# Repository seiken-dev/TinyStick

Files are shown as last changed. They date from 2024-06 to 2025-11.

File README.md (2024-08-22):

# TinyStick
<p align="center">
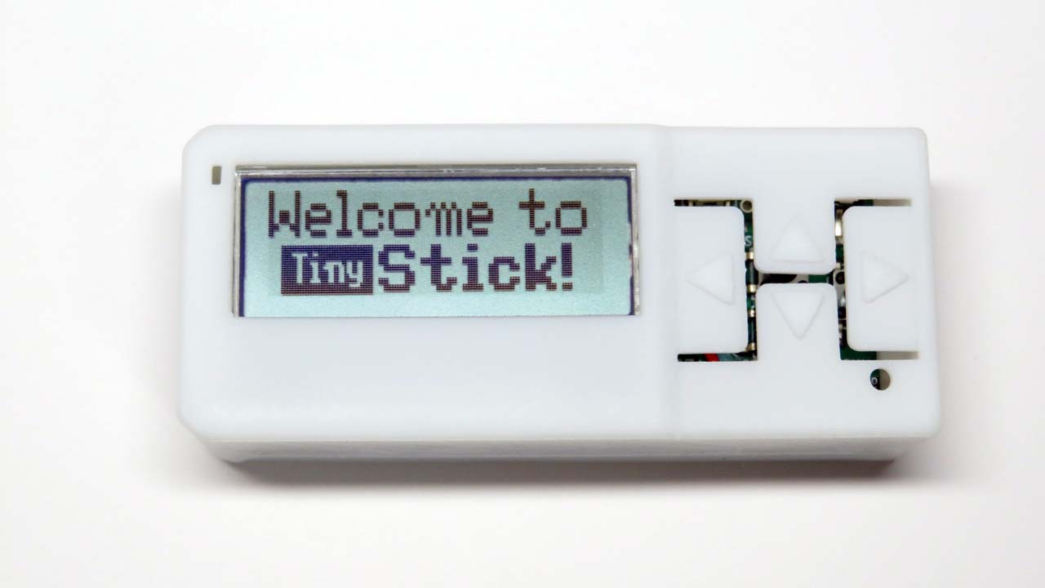
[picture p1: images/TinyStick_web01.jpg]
TinyStick

</p>

**TinyStick**は、**ATtiny3217**(32KB Flash, 2KB SRAM, 256B EEPROM)を搭載した、Arduino互換の開発キットです。消費電流は約4.5mA(クロック10MHz。スリープ時は0.1mA未満)と小さく、コイン電池で長期間動作します。プログラムの書き込みは、付属の**USBシリアル変換基板**(CH340E搭載)で行います。詳しくは、 [tinystick.jp](https://www.tinystick.jp)をご覧ください。

# コンテンツ
- **Arduino**<br>
PlatformIOでビルドできるデモのソースコードです。
- **KiCad**<br>
[KiCad](https://www.kicad.org/)(7.0)のプロジェクトです。TinyStick本体の**TS_Core.kicad_pro**と、USBシリアル変換基板の**TS_USB.kicad_pro**が含まれます。
- **schematic**<br>
TinyStick本体とUSBシリアル変換基板の回路図PDFです。
- **Blender**<br>
3Dプリントケース作成用のBlenderのプロジェクトファイルと、発注に使用したSTLファイルです。

# プログラミング
**TinyStick**のプログラミングは、[PlatformIO](https://platformio.org/)で行います。[Arduino IDE](https://www.arduino.cc/en/software)は、2.3版ではTinyAVR用のボードマネージャーの定義が読み込めない等の理由で推奨しません。(→[参考](https://ameblo.jp/pta55/entry-12835016734.html))

### ビルド
- **PlatformIO**のプロジェクトフォルダに**Arduino**以下をコピーし、適当な名前(例:TinyStickDemo)に変更します。
- **PlatformIO**の**Home**画面から[**Open Project...**]で、このプロジェクトを開きます。
- 必要なplatform(**Atmel megaAVR**)のインストールが自動的に始まります。
- インストールが完了したら**Build**してください。

### UPDI書き込み
- USBシリアル変換基板をUSBケーブルで接続して、スイッチをオンします(赤いLEDが光ります)。このとき、ドライバを自動認識しない場合は、[メーカーのHP](https://wch-ic.com/search?q=CH340&t=downloads)からCH340のドライバをダウンロードしてインストールしてください。
- Windowsの場合は、デバイスマネージャの「ポート(COMとLPT)」に「USB-SERIAL CH340 (COMxx)」と表示されれば完了です。
- **PlatformIO**の**Upload**をクリックすると、プログラムを転送します。

### シリアルデバッグ
- 横のボタン(**Button5**)を押して「Bounce Ball」デモに切り替えたあと、**PlatformIO**の**Serial Monitor**または**Tera Term**等のターミナルアプリを起動すると、加速度の数値が流れてきます。
- このUSBシリアル変換基板は、ターミナルアプリを起動するとRTS信号がLOWになることを利用して、UPDI書き込みとシリアル通信モードを自動的に切り替えます。(Windowsで確認 →[参考](https://ehbtj.com/electronics/make-serial-updi-programmer/))

### platformio.ini
プロジェクトのルートにある設定ファイルです。重要な項目について説明します。

`board_build.f_cpu = 10000000`<br>
CPUクロックを設定します。初期値は10MHz、最大は20MHzです。必ず5の倍数にしてください。そうしないとシリアル通信が文字化けします。また5MHzにすると、I2Cが正常に動作しません。記述しないと16MHzになります。

### ソースコード
- **main.cpp**<br>
メインプログラムで、初期化、タイトル表示、サイドボタン(**Button5**)によるデモの切り替え、長押しによるバックライトのオンオフを処理します。

- **TinyStickDef.h**<br>
共通の#define、ピン定義です。

- **TinyStick.h .cpp**<br>
ボタン、圧電ブザーのクラス、スリープ関連のグローバル関数です。

- **TinyLCD.h .cpp**<br>
バックライト付きLCD [**AQM1248A**](https://akizukidenshi.com/catalog/g/g110048/)に、ビットマップまたは文字を表示するクラスです。文字は、拡大・ボールド・白黒反転・縦・プロポーショナル表示に対応しています。

- **font8x8.h**<br>
8x8ドットフォントです。0x20から0x7Fまでの英数記号です。

- **TinyApp.h .cpp**<br>
複数のアプリを切り替えるときは、このクラスの派生クラスを作成して**main.cpp**に定義するだけで、サイドボタン(**Button5**)で切り替えられます。

- **I2Cbase.h .cpp**<br>
本体内蔵の加速度センサ(**LIS2DH12**)と、M5StickC用のENV Hat(**SHT30**)の基底クラスです。

- **octave.h**<br>
ドレミの周波数を定義したファイルです。

- **playDigit.h .cpp**<br>
２桁の整数値をドレミの音程で鳴らす関数です。

- **app/**<br>
6つのデモアプリです。**TinyApp**の派生クラスです。
  - **EnvHat.h .cpp**<br>
  **ENV Hat**で温度/湿度を表示します。**Button1**で次のアプリに切り替えます。装着されていないときはスキップします。

  - **KitchenTimer.h .cpp**<br>
  キッチンタイマーです。最大99分。スタートすると、分をEEPROMに保存します。

  - **AccelDemo.h .cpp**<br>
  加速度センサのデモです。傾けると玉が転がります。

  - **FontTest.h .cpp**<br>
  8x8ドットフォントをダンプします。**Button1**で拡大、**Button2,3**でスクロールします。

  - **Tetris.h .cpp**<br>
  お馴染みのゲームで、縦向きで遊びます。

  - **Maze3D.h .cpp**<br>
  Line関数を利用した3次元迷路です。

### スリープ機能
一定時間のスリープが出来ます。いずれかのボタンを押すと、スリープから復帰します。
- 時間は任意の時間ではなく、**TinyStick.h**の`enum SleepTime`の時間しか設定できません。
- 本来PX2,PX6ピンに接続されたボタン(TinyStickではButton1のみ)でしかスリープからの復帰はできませんが、これは**FALLING**モードの場合で、**LOW**モードならどのボタンでも復帰が可能です。このため、**LOW**モードでスリープし、起きたら**FALLING**モードに変更して、連続して割り込みが入らないようにしています。

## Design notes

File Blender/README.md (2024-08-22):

## Blenderのデータについて
Blenderのデータは、各パーツを結合する前のものです。Blender(3.6)の結合には次の２通りの方法があります。
- **Ctrl-J**<br>
重なった面は重複したまま残ります。
- **Bool Tool**の**Union**<br>
重なった面は削除されますが、複雑な形状だと不具合が起こりがち。

JLCPCBの[3Dプリントサービス](https://jlc3dp.com/)では、重複した面があると警告が出ますが、そのまま印刷しても問題ないようです。**Case**,**CaseBtm**のSTL出力前に、その他のパーツを上記いづれかの方法で結合してください。

### Case
- BtnEmboss1-4
- SW5Button
- PCB.Knob, 001
- PCB.Pole, 001

### CaseBtm
- CaseSide
- Edge, 001, 002<br>
  (この２つをunion)
- CaseBtmB.Knob, 001
- CaseBtmF.Knob, 001
- CaseBtmF.Pad
- MagHolder, 001, 002

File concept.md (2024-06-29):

# ATtiny3217ガジェット機能仕様
seiken 2024/03/26

## コンセプト
- ちっちゃなおもちゃが作れる
- おもちゃは電池で長持ちしなければならない
- コイン電池でも動作する
- ATtinyみたいなマイコンに触れたことがない人でもちっちゃなおもちゃが作れるような環境を実現する

## 使用例
- キッチンタイマー
- 電卓
- 寒暖計
- 赤外線リモコン
- ドアセンサー
- その他、外部と通信せずに省電力で、小さな処理で解決できそうなこと

## 外観
- M5Stick-Cのようなもの
- M5Stick-CのHATが流用できれば良い
- 上面にM5Stick互換のピンのほか、追加でIOピンを実装する
- 底面はGroveポートと、プログラム書き込みとシリアル出力のピンを実装する
- ボタンやLEDなどはM5Stickに習う

## 想定される外部接続
- I2C<br>
  各種センサーなどの接続
- SPI<br>
  SDカード、ディスプレイなどの接続
- DAC<br>
  スピーカー/ブザーの接続

## 使用マイコン
- 十分なIOがあること
- 初心者がプログラミングしてもメモリ不足にならないこと
- 十分に価格が安いこと
- 十分に実装面積が狭いこと

以上を考慮すると、ATtiny1616あるいはATtiny3217のどちらかになると思われる。

## 書き込み装置
このガジェットは、USBシリアル変換を本体には内蔵しない。電力効率の観点と、使用中はUSB機能が必須ではなくなるからである。別途、底面に装着できる書き込み装置を用意する。書き込み装置は以下の2つの機能を持つ。
- UPDI書き込み機能
- USBシリアル変換機能

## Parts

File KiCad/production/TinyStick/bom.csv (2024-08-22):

Designator | Footprint | Quantity | Value | LCSC Part #
_16, _15, _14, _13, _12, _11, _10, _9, _8, _7, _6, _5, _4, _3, _2, |  | 16
BT1 | BAT-CR2032-2 | 1 | CR2032
BZ1 | BUZ-SMD_2P-L12.0-W12.0-L | 1 | PKLCS1212E2000 | C184513
C1, C2, C3, C4, C5, C6, C7, C8, C9 | 0402 | 9 | 1u | C52923
C10, C11 | 0402 | 2 | 0.1u | C1525
C12 | 0603 | 1 | 10u | C19702
D1 | SOD-323_L1.8-W1.3-LS2.5-RD | 1 | 1N5819WS | C191023
D2 | LED0603-RD_GREEN | 1 | SML-D12P8WT86 | C510026
J3 | AQM1248A | 1 | AQM1248A
J4 | PinSocket_1x07_P2.54mm_Vertical | 1 | TinyStick_Ext1
J5 | PinSocket_1x06_P2.54mm_Vertical | 1 | TinyStick_Ext2
J6 | Grove_Connector | 1 | Grove Connector
J7 | CONN-SMD_HC-1.0-2PWT | 1 | LCD BackLight | C2845361
JP1 | SolderJumper-2_Open_mini | 1 | SolderJumper_2_Open
Q1 | AO3400A | 1 | AO3400A | C20917
R1, R2, R6, R7, R8 | 0402 | 5 | 10K | C25744
R3 | 0402 | 1 | 20K | C25765
R4 | 0402 | 1 | 100K | C25741
R5 | 0603 | 1 | 470 | C23179
RV1 | RES-ADJ-SMD_G32AT | 1 | 2K | C128118
SW1, SW2, SW3, SW4 | SW-SMD_4P-L4.5-W4.5-P3.00-LS7.5 | 4 | Tactile | C963229
SW5 | SW-SMD_BZCN_TSA002A35 | 1 | Tactile(Side) | C2846757
SW6 | SW-SMD_K3-1280S-K1 | 1 | Slide | C128953
SW7 | SW-SMD_TSD101EZ | 1 | DIP | C2758180
U1 | HVQFN-24_L4.0-W4.0-P0.50 | 1 | ATtiny3217 | C1340454
U2 | LGA-12_L2.0-W2.0-P0.50-BL | 1 | LIS2DH12 | C110926

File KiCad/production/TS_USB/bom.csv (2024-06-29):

Designator | Footprint | Quantity | Value | LCSC Part #
C1, C2 | 0603 | 2 | 10u | C19702
C3, C4 | 0402 | 2 | 0.1u | C307331
CD4053B | SOIC-16_L9.9-W3.9-P1.27-LS6.0 | 1 | CD4053B | C6742
CH340E | MSOP-10_L3.0-W3.0-P0.50-LS5.0 | 1 | CH340E | C99652
D1 | SOD-323_L1.8-W1.3-LS2.5-RD | 1 | NSR0320MW2T1G | C48192
D2 | LED0603-RD_GREEN | 1 | LED | C2693607
D3 | LED0603-RD_GREEN | 1 | LED | C510026
D4 | SOD-323_L1.8-W1.3-LS2.5-RD | 1 | 1N5819WS | C191023
J1 | USB-C-SMD_TYPE-C-16P-1 | 1 | USB_C_Receptacle_USB2.0 | C2982555
R1, R2 | 0402 | 2 | 5.1K | C25905
R3 | 0603 | 1 | 2.7K | C13167
R4, R5 | 0603 | 2 | 470 | C23179
SW1 | SW-SMD_SSSS211603 | 1 | Slide | C125040
U3 | SOT-23-5_L3.0-W1.7-P0.95-LS2.8 | 1 | ME6217C33 | C427602

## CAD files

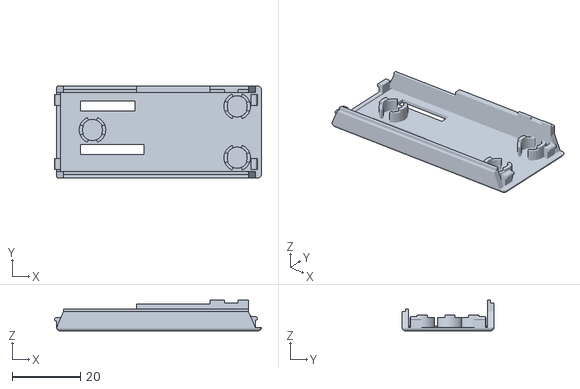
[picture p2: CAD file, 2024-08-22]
Blender/TinyStickBtm.stl
60.5 x 26.8 x 9.00

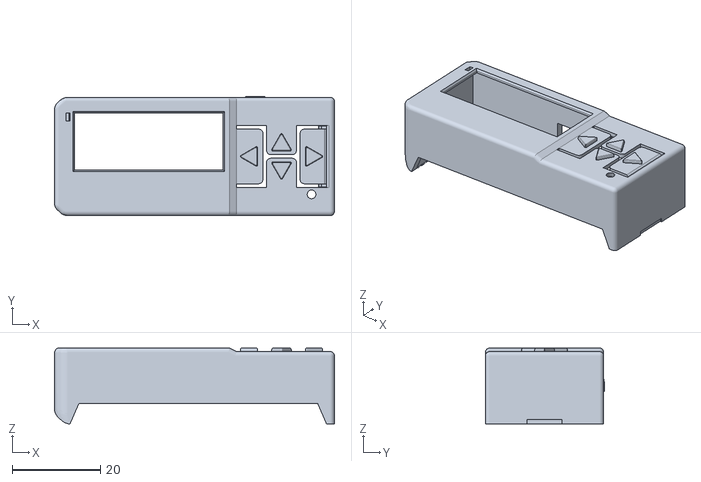
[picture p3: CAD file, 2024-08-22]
Blender/TinyStick.stl
63.4 x 27.0 x 17.2

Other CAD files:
Blender/TinyStick.blend

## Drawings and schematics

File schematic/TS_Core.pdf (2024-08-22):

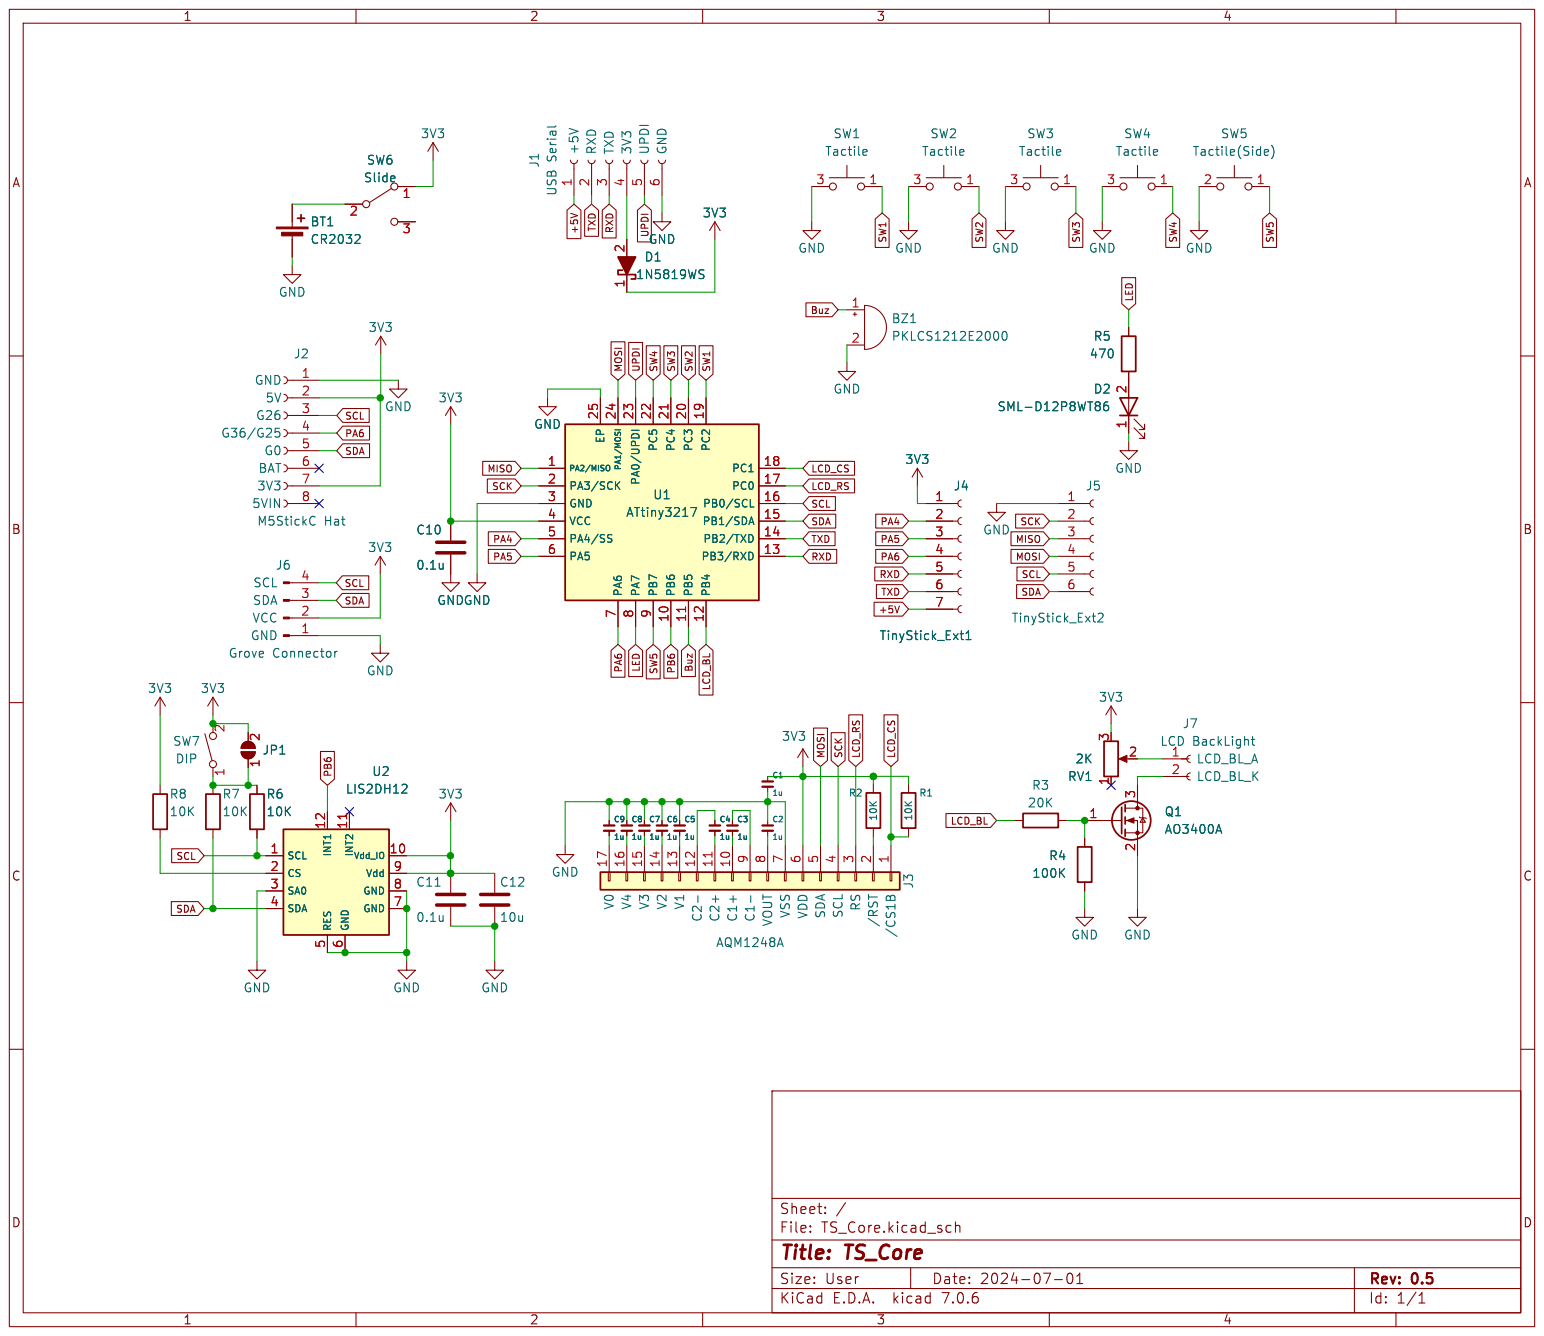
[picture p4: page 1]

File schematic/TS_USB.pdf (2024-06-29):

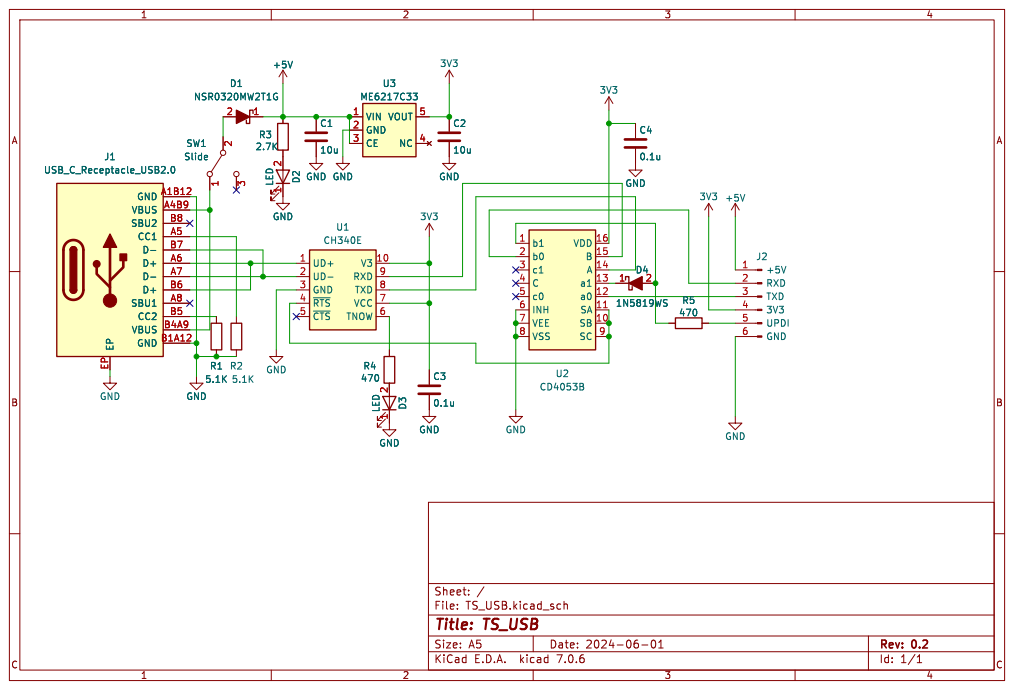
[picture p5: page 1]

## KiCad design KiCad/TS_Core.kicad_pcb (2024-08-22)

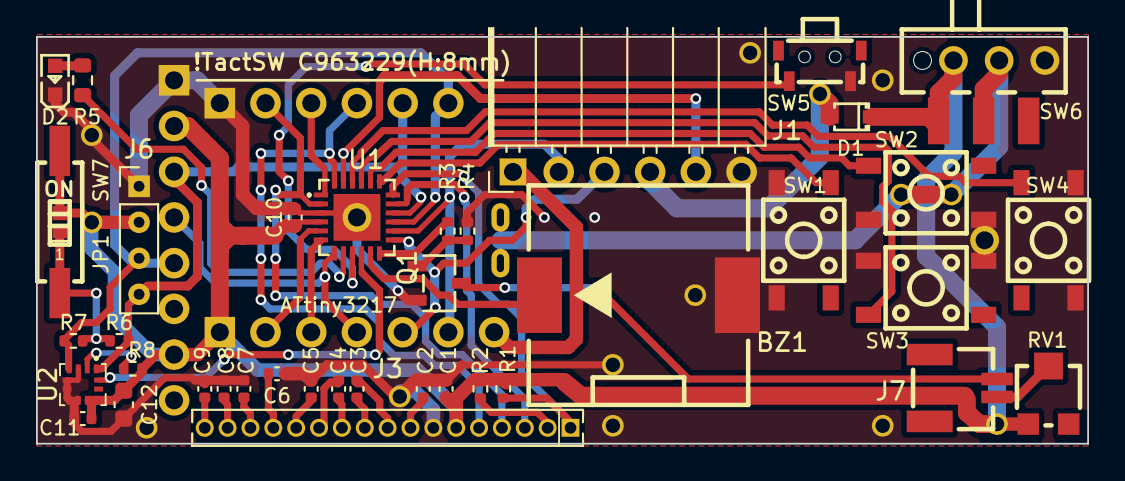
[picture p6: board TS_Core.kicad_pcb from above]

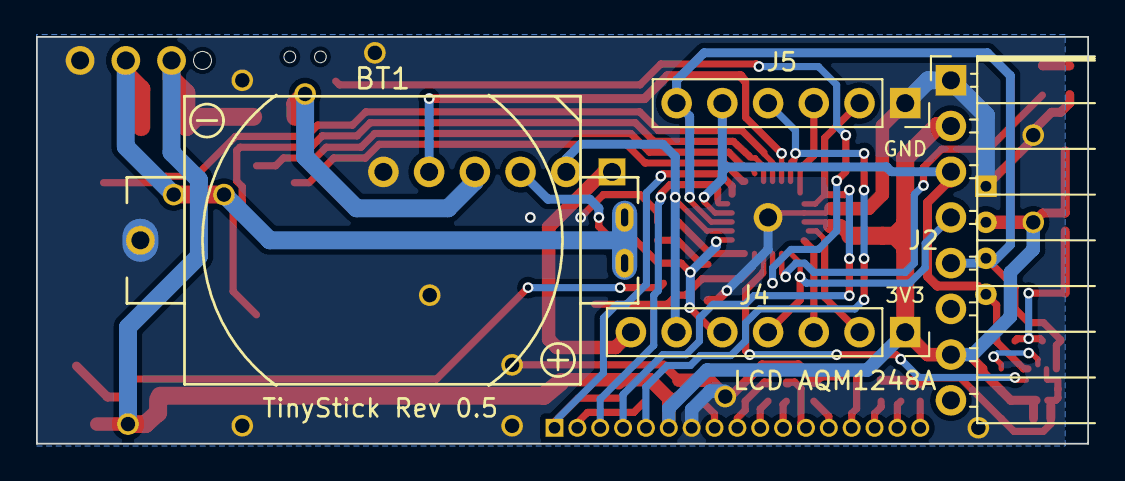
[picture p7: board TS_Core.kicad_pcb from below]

Board: 2 copper layers, 58.4 x 22.6 mm, 43 parts (4 on the bottom side), 44 nets.

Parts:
BT1: CR2032; BAT-CR2032-2
BZ1: PKLCS1212E2000; BUZ-SMD_2P-L12.0-W12.0-L
C1, C2, C3, C4, C5, C6, C7, C8, C9: 1u; C_0402_1005Metric
C10, C11: 0.1u; C_0402_1005Metric
C12: 10u; C_0603_1608Metric
D1: 1N5819WS; SOD-323_L1.8-W1.3-LS2.5-RD
D2: SML-D12P8WT86; LED0603-RD_GREEN
J1: USB Serial
J2: M5StickC Hat; PinSocket_M5StickHat
J3: AQM1248A
J4: TinyStick_Ext1; PinSocket_1x07_P2.54mm_Vertical
J5: TinyStick_Ext2; PinSocket_1x06_P2.54mm_Vertical
J6: Grove Connector; Grove_Connector
J7: LCD BackLight; CONN-SMD_HC-1.0-2PWT
JP1: SolderJumper_2_Open; SolderJumper-2_Open_mini
Q1: AO3400A
R1, R2, R6, R7, R8: 10K; R_0402_1005Metric
R3: 20K; R_0402_1005Metric
R4: 100K; R_0402_1005Metric
R5: 470; R_0603_1608Metric
RV1: 2K; RES-ADJ-SMD_G32AT
SW1, SW2, SW3, SW4: Tactile; SW-SMD_4P-L4.5-W4.5-P3.00-LS7.5
SW5: Tactile(Side); SW-SMD_BZCN_TSA002A35
SW6: Slide; SW-SMD_K3-1280S-K1
SW7: DIP; SW-SMD_TSD101EZ
U1: ATtiny3217; HVQFN-24_L4.0-W4.0-P0.50
U2: LIS2DH12; LGA-12_L2.0-W2.0-P0.50-BL

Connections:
+3V3: C1.1, C10.1, C11.1, C12.1, D1.1 (K), J2.2 (5V), J2.7 (3V3), J3.6 (VDD), J4.1, J6.2 (VCC), JP1.2 (B), R1.1, R2.1, R8.1, RV1.3, SW6.1 (A), SW7.2, U1.4 (VCC), U2.9 (Vdd), U2.10 (Vdd_IO)
+5V: J1.1 (+5V), J4.7
Buz: BZ1.1 (-), U1.11 (PB5)
GND: BT1.2 (-), BZ1.2 (+), C1.2, C2.1, C5.1, C6.1, C7.1, C8.1, C9.1, C10.2, C11.2, C12.2, D2.1 (K), J1.6 (GND), J2.1 (GND), J3.7 (VSS), J5.1, J6.1 (GND), Q1.2 (S), R4.2, SW1.3, SW1.4, SW2.3, SW2.4, SW3.3, SW3.4, SW4.3, SW4.4, SW5.2, U1.3 (GND), U1.25 (EP), U2.3 (SA0), U2.5 (RES), U2.6 (GND), U2.7 (GND), U2.8 (GND)
LCD_BL: R3.1, U1.12 (PB4)
LCD_CS: J3.1 (/CS1B), R1.2, U1.18 (PC1)
LCD_RS: J3.3 (RS), U1.17 (PC0)
LED: R5.1, U1.8 (PA7)
MISO: J5.3, U1.1 (PA2/MISO)
MOSI: J3.5 (SDA), J5.4, U1.24 (PA1/MOSI)
unnamed: BT1.1 (+), SW6.2 (B)
unnamed: D1.2 (A), J1.4 (3V3)
unnamed: D2.2 (A), R5.2
unnamed: C3.2, J3.10 (C1+)
unnamed: C3.1, J3.9 (C1-)
unnamed: C4.2, J3.11 (C2+)
unnamed: C4.1, J3.12 (C2-)
unnamed: C9.2, J3.17 (V0)
unnamed: C5.2, J3.13 (V1)
unnamed: C6.2, J3.14 (V2)
unnamed: C7.2, J3.15 (V3)
unnamed: C8.2, J3.16 (V4)
unnamed: C2.2, J3.8 (VOUT)
unnamed: J3.2 (/RST), R2.2
unnamed: J7.1 (LCD_BL_A), RV1.2
unnamed: J7.2 (LCD_BL_K), Q1.3 (D)
unnamed: JP1.1 (A), R6.1, R7.1, SW7.1
unnamed: Q1.1 (G), R3.2, R4.1
unnamed: R8.2, U2.2 (CS)
PA4: J4.2, U1.5 (PA4/SS)
PA5: J4.3, U1.6 (PA5)
PA6: J2.4 (G36/G25), J4.4, U1.7 (PA6)
PB6: U1.10 (PB6), U2.12 (INT1)
RXD: J1.3 (TXD), J4.5, U1.13 (PB3/RXD)
SCK: J3.4 (SCL), J5.2, U1.2 (PA3/SCK)
SCL: J2.3 (G26), J5.5, J6.4 (SCL), R6.2, U1.16 (PB0/SCL), U2.1 (SCL)
SDA: J2.5 (G0), J5.6, J6.3 (SDA), R7.2, U1.15 (PB1/SDA), U2.4 (SDA)
SW1: SW1.1, SW1.2, U1.19 (PC2)
SW2: SW2.1, SW2.2, U1.20 (PC3)
SW3: SW3.1, SW3.2, U1.21 (PC4)
SW4: SW4.1, SW4.2, U1.22 (PC5)
SW5: SW5.1, U1.9 (PB7)
TXD: J1.2 (RXD), J4.6, U1.14 (PB2/TXD)
UPDI: J1.5 (UPDI), U1.23 (PA0/UPDI)

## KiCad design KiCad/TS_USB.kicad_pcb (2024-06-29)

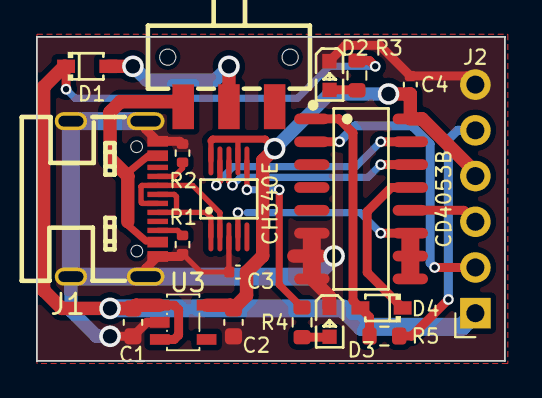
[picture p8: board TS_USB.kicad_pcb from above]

Board: 2 copper layers, 26.0 x 18.0 mm, 19 parts (0 on the bottom side), 20 nets.

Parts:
C1, C2: 10u; C_0603_1608Metric
C3, C4: 0.1u; C_0402_1005Metric
CD4053B: CD4053B; SOIC-16_L9.9-W3.9-P1.27-LS6.0
CH340E: CH340E; MSOP-10_L3.0-W3.0-P0.50-LS5.0
D1: NSR0320MW2T1G; SOD-323_L1.8-W1.3-LS2.5-RD
D2, D3: LED; LED0603-RD_GREEN
D4: 1N5819WS; SOD-323_L1.8-W1.3-LS2.5-RD
J1: USB_C_Receptacle_USB2.0; USB-C-SMD_TYPE-C-16P-1
J2: Conn_01x06_Pin; PinHeader_1x06_P2.54mm
R1, R2: 5.1K; R_0402_1005Metric
R3: 2.7K; R_0603_1608Metric
R4, R5: 470; R_0603_1608Metric
SW1: Slide; SW-SMD_SSSS211603
U3: ME6217C33; SOT-23-5_L3.0-W1.7-P0.95-LS2.8

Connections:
+3V3: C2.1, C3.1, C4.1, CD4053B.16 (VDD), CH340E.7 (VCC), CH340E.10 (V3), J2.4 (3V3), U3.5 (VOUT)
+5V: C1.1, D1.1 (K), J2.1 (+5V), R3.1, U3.1 (VIN), U3.3 (CE)
GND: C1.2, C2.2, C3.2, C4.2, CD4053B.6 (INH), CD4053B.7 (VEE), CD4053B.8 (VSS), CH340E.3 (GND), D2.1 (K), D3.1 (K), J1.A1B12 (GND), J1.B1A12 (GND), J1.EP, J2.6 (GND), R1.2, R2.2, U3.2 (GND)
unnamed: D1.2 (A), SW1.2 (B)
unnamed: D2.2 (A), R3.2
unnamed: D3.2 (A), R4.2
unnamed: CD4053B.1 (b1), D4.2 (A), R5.2
unnamed: CD4053B.13 (a1), D4.1 (K)
unnamed: J1.A5 (CC1), R2.1
unnamed: J1.B5 (CC2), R1.1
unnamed: CD4053B.2 (b0), J2.2 (RXD)
unnamed: CD4053B.12 (a0), J2.3 (TXD)
unnamed: J2.5 (UPDI), R5.1
unnamed: J1.A4B9 (VBUS), J1.B4A9 (VBUS), SW1.1 (A)
unnamed: CD4053B.15 (B), CH340E.9 (RXD)
unnamed: CH340E.6 (TNOW), R4.1
unnamed: CD4053B.14 (A), CH340E.8 (TXD)
unnamed: CH340E.1 (UD+), J1.A6 (D+), J1.B6 (D+)
unnamed: CH340E.2 (UD-), J1.A7 (D-), J1.B7 (D-)
unnamed: CD4053B.9 (SC), CD4053B.10 (SB), CD4053B.11 (SA), CH340E.4 (~RTS)

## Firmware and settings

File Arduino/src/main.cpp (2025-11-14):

#include "TinyStick.h"
#include "TinyLCD.h"
#include "TinyApp.h"
#include "font8x8.h"

// Simply list the TinyApp derived classes and switch them in order.

#include "app/EnvHat.h"
EnvHat envHat;

#include "app/KitchenTimer.h"
KitchenTimer kitchenTimer;

#include "app/AccelDemo.h"
AccelDemo accelDemo;

#include "app/FontTest.h"
FontTest fontTest;

#include "app/Tetris.h"
Tetris tetris;

#include "app/Maze3D.h"
Maze3D maze3D;

void drawTitle() {
	LCD.clear();
	LCD.setTextProp(true);
	LCD.setTextScale(2, 3);
	LCD.print(0, 0, "Welcome to");
	LCD.fillRect(5, 25, 35, 22);
	LCD.setTextStyle(true, true);
	LCD.setTextScale(1, 2);
	LCD.print(9, 28, "Tiny");
	LCD.setTextStyle(true);
	LCD.setTextScale(2, 3);
	LCD.print(42, 25, "Stick!");
	LCD.flush();
	LCD.reset();
}

void flash(uint16_t ms = 20) {
	digitalWrite(PIN_LED, HIGH);
	delay(ms);
	digitalWrite(PIN_LED, LOW);
}

//
// setup
//
void setup() {
	pinMode(PIN_LED, OUTPUT);
	delay(100);

#ifdef DEBUG_SERIAL
    Serial.begin(115200);
#endif

	LCD.begin(PIN_LCD_RS, PIN_LCD_CS, PIN_LCD_BL);
#ifdef LCD_TEXT_PROP
	LCD.setFont(font8x8, font8x8_width);
#else
	LCD.setFont(font8x8);
#endif

	Button::init();
	buzzer.begin();

	drawTitle();
	delay(200);
	digitalWrite(PIN_LED, HIGH);
	buzzer.beep(2000, 150);
	buzzer.beep(1000, 150);
	digitalWrite(PIN_LED, LOW);
	delay(500);

	TinyApp::startApp(0);

#ifdef DEBUG_SERIAL
	Serial.println("start");
#endif
}

//
// loop
//
#define MIN_DELAY 20

void loop() {
	unsigned long tick = millis();

	Button::updateAll();

	if (btnSide.wasPressed()) {
		buzzer.click();
	}
	if (btnSide.wasLongPressed()) {
		LCD.backLight(!LCD.isBackLight());
		Serial.printf("BL=%d\n", LCD.isBackLight());
		btnSide.waitForRelease();
	} else if (btnSide.wasReleased()) {
		TinyApp::nextApp();
	} else {
		TinyApp* app = TinyApp::getApp();
		if (app && app->toNextApp()) {
			buzzer.click();
			TinyApp::nextApp();
		}
	}

	TinyApp::updateApp();

	flash();
	unsigned long elapse = millis() - tick;
	if (elapse < MIN_DELAY) {
		delay(MIN_DELAY - elapse);
	}
}

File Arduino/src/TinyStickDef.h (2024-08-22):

#pragma once

#define DEBUG_SERIAL

#define BUTTONS_COUNT 5

#define TS_SLEEP // sleep support
#define LCD_VERTICAL // vertical mode
#define LCD_TEXT_PROP // proportional
#define LCD_DRAW_LINE

//#define PLAY_DIGIT // play digit by tone
#define USE_EEPROM // save settings in EEPROM

#define EEPROM_KITCHEN_TIMER_MINUTE 1

#define PIN_LED PIN_PA7
#define PIN_BUZZER PIN_PB5

#define PIN_LCD_RS PIN_PC0
#define PIN_LCD_CS PIN_PC1
#define PIN_LCD_BL PIN_PB4

#define PIN_BUTTON1 PIN_PC2
#define PIN_BUTTON2 PIN_PC3
#ifdef ARDUINO_attinyxy7
  #define PIN_BUTTON3 PIN_PC4
  #define PIN_BUTTON4 PIN_PC5
#else
  #define PIN_BUTTON3 PIN_PB4
  #define PIN_BUTTON4 PIN_PB5
#endif

#if (BUTTONS_COUNT == 5)
  #define btnSide btn5
  #ifdef ARDUINO_attinyxy7
    #define PIN_BUTTON5 PIN_PB7
  #else
    #define PIN_BUTTON5 PIN_PA5
  #endif
#else
  #define btnSide btn4
#endif

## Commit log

2024-08-22 update 5 buttons
    [TS_Core.kicad_pcb, TS_Core.kicad_sch, TinyStick.blend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]
2025-11-14 fix: remove unused variable and adjust elapse calculation in loop.
    [main.cpp]
